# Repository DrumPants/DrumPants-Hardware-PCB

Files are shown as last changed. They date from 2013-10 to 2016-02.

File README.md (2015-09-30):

DrumPants Wearable Controller PCB
================================================

DrumPants is a wearable musical instrument and controller. 

http://www.drumpants.com

For firmware source code, see http://developers.drumpants.com

Features
--------------------------

* Sends MIDI messages over native USB 
* Bluetooth module
* MIDI synthesizer chip
* I2C EEPROM Storage
* 7-segment LED Display 
* Encoder knob and volume buttons
* Arduino Due Compatible

Credits
==========================

* Electrical Engineering and Design: Shaun Houlihan / Hedlabs (http://www.hedlabs.com/)
* Architecture and Firmware Engineering: Tyler Freeman / DrumPants
* Industrial Design: John Sundermeyer / Pull Creative (http://www.pullcreative.com)
* Sensor Design and Manufacturing: Lei Yu / DrumPants

Based on the Arduino Due

License
==========================

Copyright 2013-2015 DrumPants, Inc.
  
http://www.drumpants.com

Please see LICENSE.txt for copying and licensing info.

Licensed under the Creative Commons Attribution-ShareAlike license:

    http://creativecommons.org/licenses/by-sa/3.0/legalcode

Unless required by applicable law or agreed to in writing, software
distributed under the License is distributed on an "AS IS" BASIS,
WITHOUT WARRANTIES OR CONDITIONS OF ANY KIND, either express or implied.
See the License for the specific language governing permissions and
limitations under the License.

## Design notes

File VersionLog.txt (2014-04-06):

----IN WORK VERSION

PCB Version A0
Case Version A0

----CHANGES TO MAKE

resistor values for display change
resistor values for inputs change

----CHANGES MADE
Remove JTAG
Rename encoder nets
Ground encoder common
Bluetooth enable pin to digital IO
Added Tab Holes for USB Connector
Cutouts on PCB for Encoder
Fix power nets
Add battery solder pads

----FUTURE CHANGES

REMOVE RTC CRYSTAL?
SMALLER MCU PACKAGE
SMALLER SMD DISPLAY
SMALLER ENCODER
ENCODER POWER ON/OFF

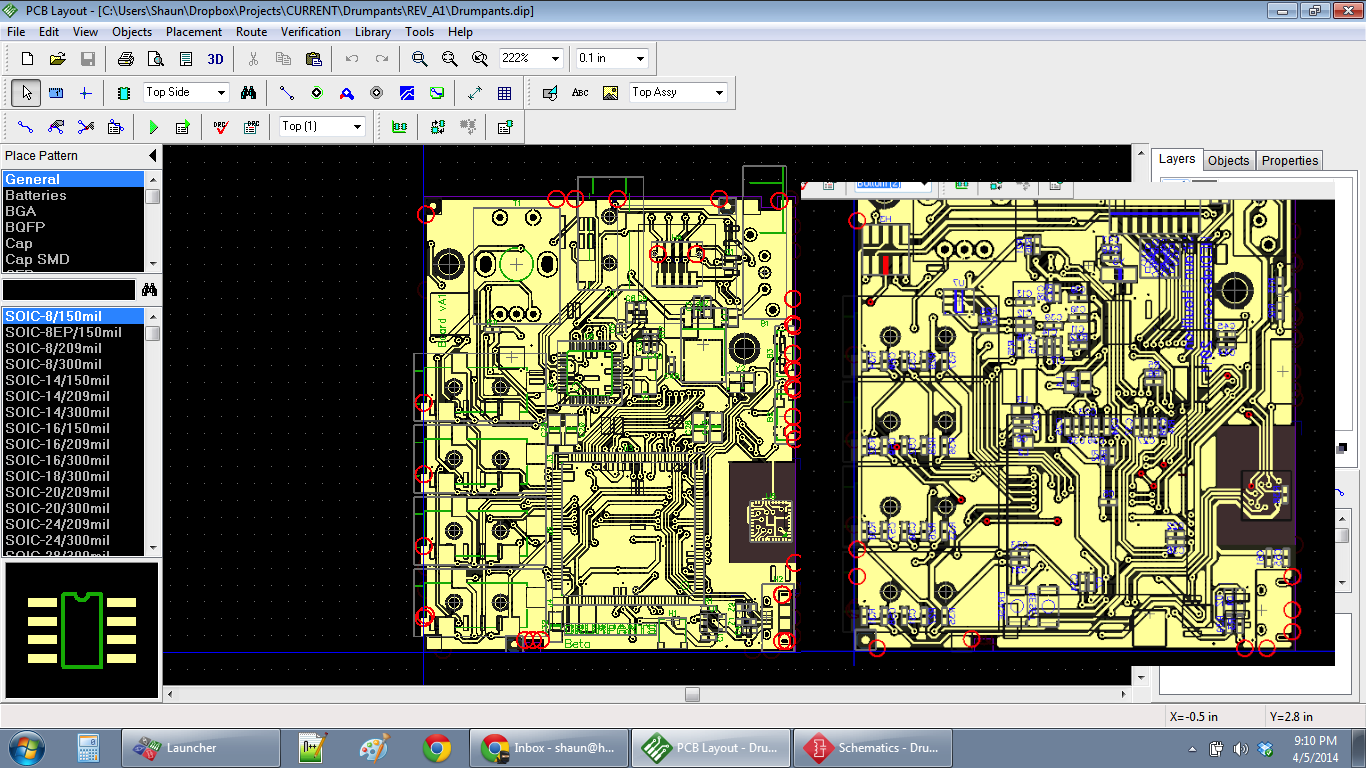
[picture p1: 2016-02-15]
beta board A1 - layout TOP.png

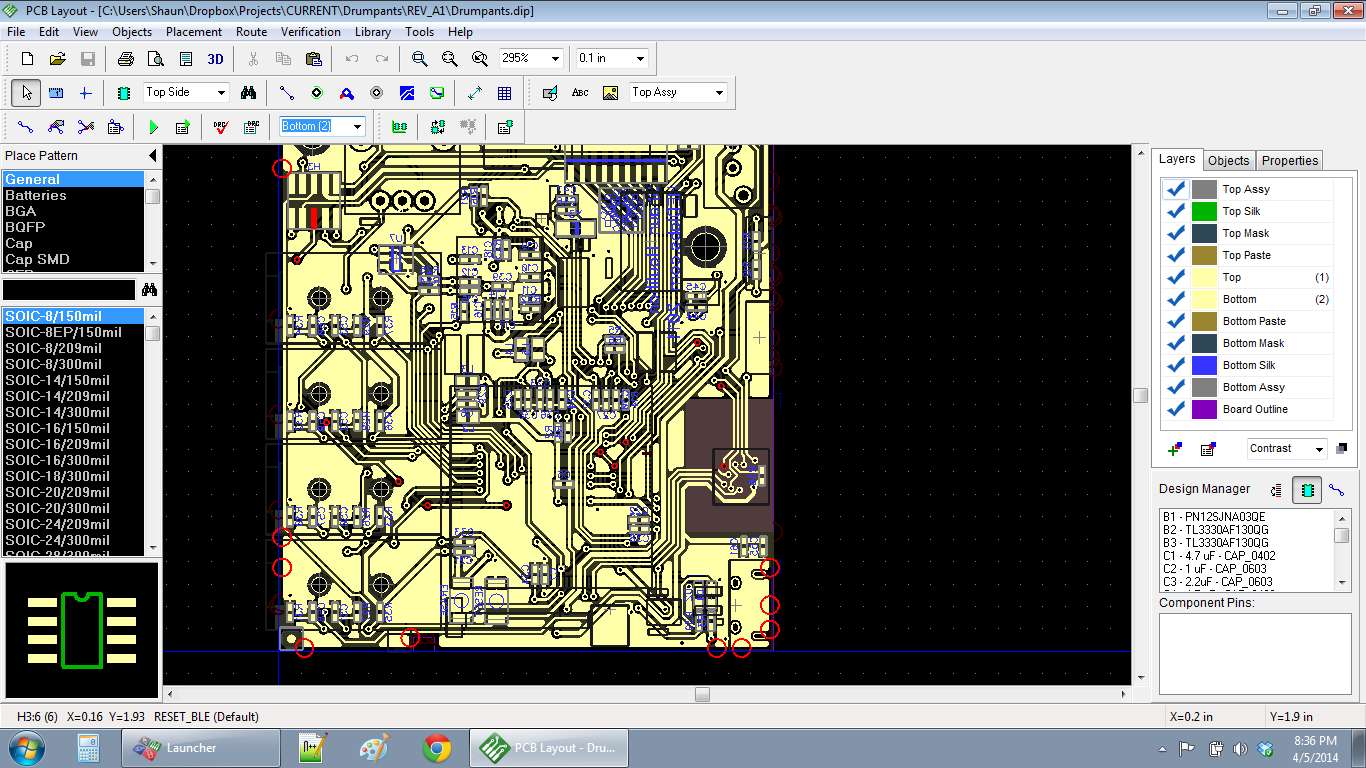
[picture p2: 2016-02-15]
beta board A1 - layout BOTTOM.png

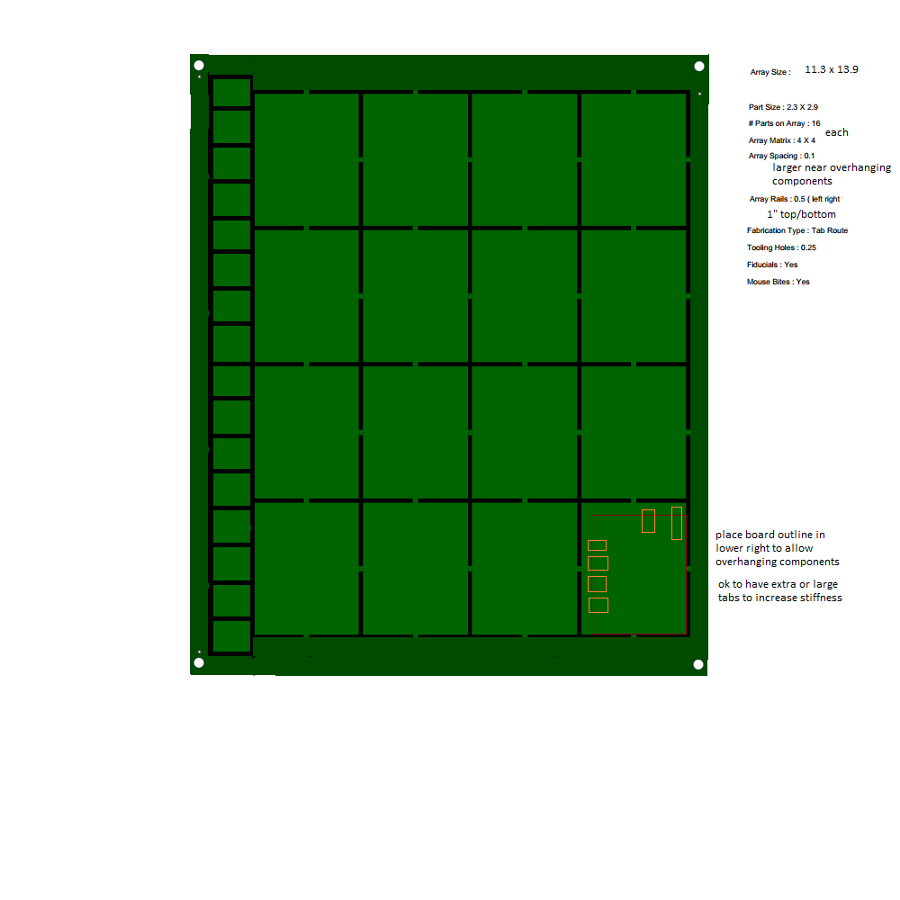
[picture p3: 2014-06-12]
panel.png

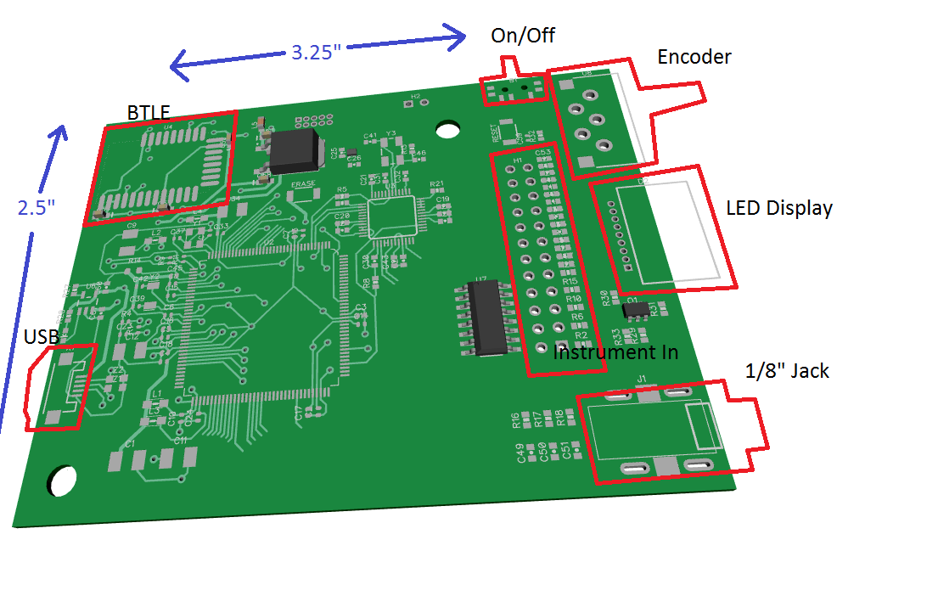
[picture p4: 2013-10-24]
Records/Layout3D.png

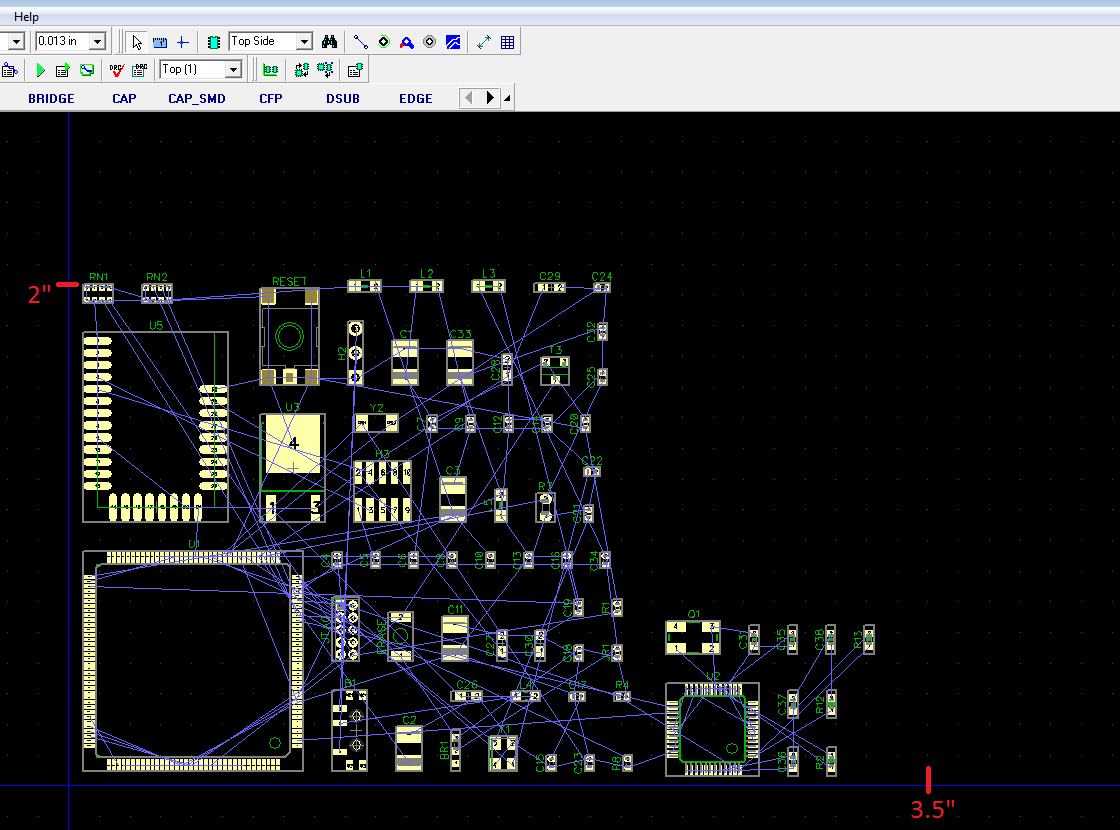
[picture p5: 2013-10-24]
Records/InitialSizing.png

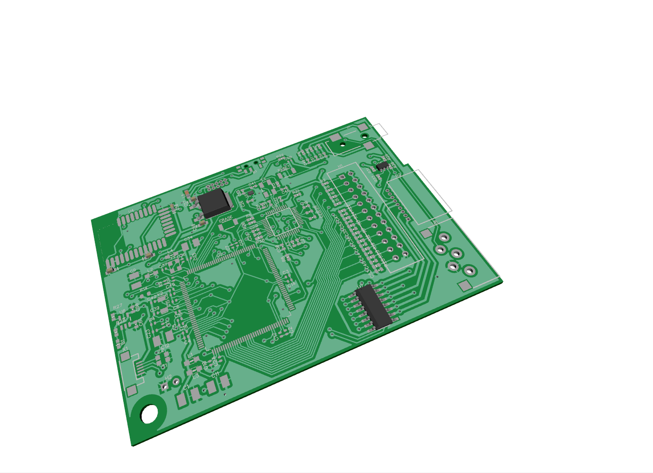
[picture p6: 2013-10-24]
Records/3D_10-24-2013.png

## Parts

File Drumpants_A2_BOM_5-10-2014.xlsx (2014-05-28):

RefDes | Name | Quantity | Value | Pattern | Pattern Type | Manufacturer | Mfg Part Number | Reel Size
B1 | SWITCH PUSH SPDT 0.3A 30V | 1 | LC1258EENP | LC1258EENP | THRU | E-Switch | LC1258EENP | 1600
D1 | LED_0603 YELLOW | 1 | LTST-C190KSKT | DIODE_0603 | SMD | Lite-On | LTST-C190KSKT | 3000
D2 | LED_0603 GREEN | 1 | LTST-C190GKT | DIODE_0603 | SMD | Lite-On | LTST-C190GKT | 3000
B2, B3 | SWITCH TACTILE SPST-NO 0.05A 12V | 2 | TL3330AF130QG | TL3330AF130QG | SMD | E-Switch (http://www.e-switch.com/) | TL3330AF130QG | 2300
C1, C4, C55 | CAP_0402 | 3 | 4.7 uF | CAP_0402 | SMD | Samsung EM | CL05A475MQ5NRNC | 10000
C2, C8, C9 | CAP_0603 | 3 | 1 uF | CAP_0603 | SMD | Samsung EM | CL10B105KQ8NNNC | 4000
C20, C26, C28, C32, C49 | CAP TANT 10UF 6.3V 10% 1206 | 5 | 10 uF | CAP_1206 | SMD | Kemet (http://www.kemet.com/) | T491A106K006AT7280 | 9000
C3 | CAP_0603 | 1 | 2.2uF | CAP_0603 | SMD
C30, C44, C45 | CAP_0402 | 3 | 22 pF | CAP_0402 | SMD
C31, C40 | CAP_0402 | 2 | 18pF | CAP_0402 | SMD
C41 | CAP_0402 | 1 | 0.047 uF | CAP_0402 | SMD
C5, C42, C43 | CAP_0402 | 3 | 10k pF | CAP_0402 | SMD
C50, C51, C52, C53, C57, C58, C59, C60 | CAP_0402 | 8 | 10 pF | CAP_0402 | SMD
C6, C7, C10, C11, C12, C13, C14, C15, C16, C17, C18, C19, C21, C22, C23, C24, C25, C27, C29, C33, C34, C35, C36, C37, C38, C39, C48, C61 | CAP_0402 | 28 | 0.1 uF | CAP_0402 | SMD
D100 | 0.3" DOUBLE DIGIT RED SMD LED | 1 | ACDA03 | ACDA04 | SMD | Kingbright (http://www.kingbrightusa.com/) | ACDA03-41SYKWA-F01 | 300
H100 | CONN HEADER 10POS DUAL SHRD SMD | 1 | 20021221-00010C4LF | 1.27MM PITCH 2x5 | SMD | FCI (http://www.te.com/en/home.html) | 20021221-00010C4LF | 500
H2 | CONN USB MICRO B RECPT SMT R/A | 1 | 10118194-0001LF | USB MICRO B 10118194-0001LF | SMD | FCI (http://portal.fciconnect.com/portal/page/portal/fciconnect/homepage) | 10118194-0001LF | 1200
H4 | CONN HEADR 0.049" 10POS SMT TIN | 1 | 20021121-00010T4LF | 1.27MM PITCH 2x5 | SMD | FCI (http://www.te.com/en/home.html) | 20021121-00010T4LF | N/A
H5 | CONN HEADER 3POS 1.25MM R/A SMD | 1 | 532610371 | 532610371 | SMD | Molex | 532610371 | 1000
J1 | CONN JACK STEREO 3.5MM SMD | 1 | 35RASMT2BHNTRX | SJ-3503-SMT-TR | SMD | Switchcraft Inc. (http://www.switchcraft.com/) | 35RASMT2BHNTRX | 1100
J2, J3, J4, J5 | CONN AUDIO JACK 3.5MM 4COND SMD | 4 | SJ-43515TS-SMT-TR | SJ-43515TS-SMT-TR | SMD | CUI Inc. (http://www.cui.com/) | SJ-43515TS-SMT-TR | 2000
L1 | FERRITE CHIP 1000 OHM 500MA 0805 | 1 | FB 1kOhm | IND_0805 | SMD | Samsung EM | CIM21J102NE | 4000
L2, L3, L4, L5 | BEAD FERRITE 30 OHM 3A | 4 | MH2029-300Y | IND_0805 | SMD | Bourns Inc. (http://www.bourns.com/) | MH2029-300Y | 4000
Q1 | TRANS DUAL NPN 30V 1A 6HUSON | 1 | PBSS4130PAN,115 | SOT1118 | LEADLESS | NXP (http://www.nxp.com/) | PBSS4130PAN,115 | 3000
R1 | RES_0402 | 1 | 2k | RES_0402 | SMD
R14 | RES_0402 | 1 | 6k8 | RES_0402 | SMD
R18 | RES_0402 | 1 | 10 | RES_0402 | SMD
R19, R20 | RES_0402 | 2 | 20 | RES_0402 | SMD
R2, R15, R16, R17, R21, R22, R23 | RES_0402 | 7 | 100k | RES_0402 | SMD
R24, R25 | RES_0402 | 2 | 10k | RES_0402 | SMD
R26, R27, R28, R29, R30, R31, R32, R34 | RES_0402 | 8 | 1M | RES_0402 | SMD
R33, R35, R36, R37 | RES_0402 | 4 | 470 | RES_0402 | SMD
R5, R6 | RES_0402 | 2 | 39 | RES_0402 | SMD
R7, R10, R3, R39 | RES_0402 | 4 | 100 | RES_0402 | SMD
R8, R9, R11, R12, R13 | RES_0402 | 5 | 4k7 | RES_0402 | SMD
T1 | 11mm Rotary Encoder | 1 | ACZ11BR4E-15FD1-20C | ACZ11BR4E | THRU | BI Technologies (http://www.bitechnologies.com/) | EN11-HSB1AQ15 | N/A
U1 | IC CONTROLLR LI-ION 4.2V SOT23-5 | 1 | MCP73831 | SOT23-5 | SMD | Microchip (http://www.microchip.com/) | MCP73831T-2ACI/OT | 3000
U2 | IC REG LDO 3.3V 0.8A DPAK | 1 | LD39080DT33-R | TO252-3(4)/10x6.6x2.28 | SMD | STMicro (http://www.st.com/web/en/home.html) | LD39080DT33-R | 2500
U3 | IC MCU 32BIT 512KB FLASH 144LQFP | 1 | ATSAM3X8EA-AU | 144LQFP | SMD | Atmel (http://www.atmel.com/) | ATSAM3X8EA-AU | N/A
U4 | TRANS 8 NPN DARL 50V 500MA 18SOL | 1 | ULN2803A | SOIC-18/300mil | SMD | Toshiba Semicond (http://www.toshiba.com/taec/) | ULN2803AFWG(C,ELHA | 1000
U5 | IC REG LDO 1.8V 0.2A 6XSON | 1 | LD6806F/18P,115 | SOT886 | LEADLESS | NXP (http://www.nxp.com/) | LD6806F/18P,115 | 5000
U6 | VS1053 | 1 | VS1053 | LQFP-48 | SMD | VLSI (http://www.vlsi.fi/en/home.html) | VS1053 | 1000
U7 | IC EEPROM 4KBIT 400KHZ SOT23-5 | 1 | 24LC04BT-I/OT | SOT-23-5 | SMD | Microchip | 24LC04BT-I/OT | 3000
U8 | BCM20732S | 1 | BCM20732S | BCM20732S | LEADLESS | Broadcom (http://www.broadcom.com/) | BCM20732S | 377
Y1 | CRYSTAL 12.288MHZ 20PF SMD | 1 | 7B-12.288MBBK-T | CRYSTAL-SMD-5X3 | SMD | TXC Corporation (http://www.txc.com.tw/en/index.asp) | 7B-12.288MBBK-T | 1000
Y2 | CRYSTAL 12MHZ 12PF SMD | 1 | 7V-12.000MAAE-T | TXC7V | SMD | TXC Corporation (http://www.txc.com.tw/en/index.asp) | 7V-12.000MAAE-T | 3000
Z1, Z2 | VARISTOR_0603 | 2 | CG0603MLC-05E | VARISTOR_0603 | SMD | Bourns Inc. (http://www.bourns.com/) | CG0603MLC-05E | 5000

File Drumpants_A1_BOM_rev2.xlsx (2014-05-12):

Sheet: BOARD
RefDes | Name | Quantity | Value | Pattern | Pattern Type | Manufacturer | Mfg Part Number | Reel Size | Reqd Reels | Extra From Reel | Distributer A | Distributer A Part Number | Price/Reel A | Reel Price Ext A | Price/Each A | Ind Price Ext A | Lead Time Wks A | Distributer B | Distributer B Part Number | Price/Reel B | Price Ext B | Lead Time Wks B | Cheapest Price
C6, C7, C10, C11, C12, C13, C14, C15, C16, C17, C18, C19, C21, C22, C23, C24, C25, C27, C29, C33, C34, C35, C36, C37, C38, C39, C48, C61 | CAP_0402 | 27 | 0.1 uF | CAP_0402 | SMD | Samsung EM | CL05A104MP5NNNC | 10000 | 3 | 3000 | Digikey | 1276-1443-2-ND | $21.00 | $63.00 | $0.003 | $81.00 | 0 |  |  |  |  |  | $21.00
C50, C51, C52, C53, C57, C58, C59, C60 | CAP_0402 | 8 | 10 pF | CAP_0402 | SMD | Samsung EM | CL05C100JB5NNNC | 10000 | 1 | 2000 | Digikey | 1276-1139-2-ND | $22.68 | $22.68 | $0.00324 | $25.92 | 0 |  |  |  |  |  | $22.68
R26, R27, R28, R29, R30, R31, R32, R34 | RES_0402 | 8 | 1M | RES_0402 | SMD | Samsung EM | RC1005J105CS | 10000 | 1 | 2000 | Digikey | 1276-4448-2-ND | $13.04 | $13.04 | $0.0023 | $18.40 | 0 |  |  |  |  |  | $13.04
R2, R15, R16, R17, R21, R22, R23 | RES_0402 | 7 | 100k | RES_0402 | SMD | Samsung EM | RC1005F104CS | 10000 | 1 | 3000 | Digikey | 1276-3432-2-ND | $14.36 | $14.36 | $0.0035 | $24.50 | 0 |  |  |  |  |  | $14.36
C2, C8, C9 | CAP_0603 | 6 | 1 uF | CAP_0603 | SMD | Samsung EM | CL10B105KQ8NNNC | 4000 | 2 | 2000 | Digikey | 1276-1024-2-ND | $31.28 | $62.56 | $0.01 | $61.20 | 0 |  |  |  |  |  | $31.28
C30, C44, C45, C46, C47 | CAP_0402 | 5 | 22 pF | CAP_0402 | SMD | Samsung EM | CL05C220JB5NNNC | 10000 | 1 | 5000 | Digikey | 1276-1116-2-ND | $22.68 | $22.68 | $0.00324 | $16.20 | 0 |  |  |  |  |  | $16.20
C20, C26, C28, C32, C49 | CAP TANT 10UF 6.3V 10% 1206 | 5 | 10 uF | CAP_1206 | SMD | Kemet (http://www.kemet.com/) | T491A106K006AT7280 | 9000 | 1 | 4000 | Digikey | 399-10116-2-ND | $576.00 | $576.00 | $0.09 | $460.00 | 0 |  |  |  |  |  | $460.00
R8, R9, R11, R12, R13 | RES_0402 | 5 | 4k7 | RES_0402 | SMD | Samsung EM | RC1005J472CS | 10000 | 1 | 5000 | Digikey | 1276-4392-2-ND | $13.04 | $13.04 | $0.00254 | $12.70 | 0 |  |  |  |  |  | $12.70
L2, L3, L4, L5 | BEAD FERRITE 30 OHM 3A | 4 | MH2029-300Y | IND_0805 | SMD | Bourns Inc. (http://www.bourns.com/) | MH2029-300Y | 4000 | 1 | 0 | Digikey | MH2029-300YCT-ND | $61.44 | $61.44 | $0.02 | $80.24 | no reels stock |  |  |  |  |  | $61.44
R33, R35, R36, R37 | RES_0402 | 4 | 470 | RES_0402 | SMD | Samsung EM | RC1005F471CS | 10000 | 1 | 6000 | Digikey | 1276-3989-2-ND | $14.36 | $14.36 | $0.00254 | $10.16 | 0 |  |  |  |  |  | $10.16
J2, J3, J4, J5 | CONN AUDIO JACK 3.5MM 4COND SMD | 4 | SJ-43515TS-SMT-TR | SJ-43515TS-SMT-TR | SMD | CUI Inc. (http://www.cui.com/) | SJ-43515TS-SMT-TR | 2000 | 2 | 0 | Digikey | CP-43515TSSJTR-ND | $1067.20 | $2134.40 | $0.73 | $2914.56 | 0 | Future Electronics |  |  |  |  | $1067.20
R3, R7, R10, R39 | RES_0402 | 3 | 680 | RES_0402 | SMD | Samsung EM | RC1005J681CS | 10000 | 1 | 7000 | Digikey | 1276-4372-2-ND | $13.04 | $13.04 | $0.00254 | $7.62 | 0 |  |  |  |  |  | $7.62
C1, C4, C55 | CAP_0402 | 3 | 4.7 uF | CAP_0402 | SMD | Samsung EM | CL05A475MQ5NRNC | 10000 | 1 | 7000 | Digikey | 1276-1056-2-ND | $366.70 | $366.70 | $0.05 | $147.66 | 0 |  |  |  |  |  | $147.66
C5, C42, C43 | CAP_0402 | 2 | 10k pF | CAP_0402 | SMD | Samsung EM | CL05B103KB5NNNC | 10000 | 1 | 8000 | Digikey | 1276-1028-2-ND | $21.63 | $21.63 | $0.00309 | $6.18 | 0 |  |  |  |  |  | $6.18
C31, C40 | CAP_0402 | 2 | 18pF | CAP_0402 | SMD | Samsung EM | CL05C180JB5NNNC | 10000 | 1 | 8000 | Digikey | 1276-1140-2-ND | $22.68 | $22.68 | $0.00324 | $6.48 | 0 |  |  |  |  |  | $6.48
R5, R6 | RES_0402 | 2 | 39 | RES_0402 | SMD | Samsung EM | RC1005F390CS | 10000 | 1 | 8000 | Digikey | 1276-3463-2-ND | $14.85 | $14.85 | $0.00254 | $5.08 | 0 |  |  |  |  |  | $5.08
R19, R20 | RES_0402 | 2 | 20 | RES_0402 | SMD | Samsung EM | RC1005J200CS | 10000 | 1 | 8000 | Digikey | 1276-4335-2-ND | $13.04 | $13.04 | $0.00254 | $5.08 | 0 |  |  |  |  |  | $5.08
R24, R25, R38 | RES_0402 | 2 | 10k | RES_0402 | SMD | Samsung EM | RC1005F103CS | 10000 | 1 | 8000 | Digikey | 1276-3431-2-ND | $14.36 | $14.36 | $0.00254 | $5.08 | 0 |  |  |  |  |  | $5.08
B2, B3 | SWITCH TACTILE SPST-NO 0.05A 12V | 2 | TL3330AF130QG | TL3330AF130QG | SMD | E-Switch (http://www.e-switch.com/) | TL3330AF130QG | 2300 | 1 | 300 | Digikey | EG4388TR-ND | $520.95 | $520.95 | $0.25 | $498.30 | 0 |  |  |  |  |  | $498.30
Z1, Z2 | VARISTOR_0603 | 2 | CG0603MLC-05E | VARISTOR_0603 | SMD | Bourns Inc. (http://www.bourns.com/) | CG0603MLC-05E | 5000 | 1 | 3000 | Digikey | CG0603MLC-05ETR-ND | $390.00 | $390.00 | $0.10 | $206.96 | 0 |  |  |  |  |  | $206.96
J1 | CONN JACK STEREO 3.5MM SMD | 1 | 35RASMT2BHNTRX | SJ-3503-SMT-TR | SMD | Switchcraft Inc. (http://www.switchcraft.com/) | 35RASMT2BHNTRX | 1100 | 1 | 100 | Digikey | 35RASMT2BHNTRX | $646.80 | $646.80 | $0.61 | $610.00 | 0 |  |  |  |  |  | $610.00
Y1 | CRYSTAL 12.288MHZ 20PF SMD | 1 | 7B-12.288MBBK-T | CRYSTAL-SMD-5X3 | SMD | TXC Corporation (http://www.txc.com.tw/en/index.asp) | 7B-12.288MBBK-T | 1000 | 1 | 0 | Digikey | 887-1892-2-ND | $390.00 | $390.00 | $0.49 | $491.40 | 0 |  |  |  |  |  | $390.00
Y2 | CRYSTAL 12MHZ 12PF SMD | 1 | 7V-12.000MAAE-T | TXC7V | SMD | TXC Corporation (http://www.txc.com.tw/en/index.asp) | 7V-12.000MAAE-T | 3000 | 1 | 2000 | Digikey | 887-1458-1-ND | $1305.00 | $1305.00 | $0.47 | $474.00 | 0 |  |  |  |  |  | $474.00
H4 | CONN HEADR 0.049" 10POS SMT TIN | 1 | 4-174821-0 | 1.25MM PITCH 2x5 | SMD | TE Connectivity (http://www.te.com/en/home.html) | 4-174821-0 | N/A | #VALUE! | #VALUE! | Digikey | 4-174821-0-ND | N/A | $0.00 | $0.36 | $356.40 | 0 |  |  |  |  |  | $356.40
U3 | IC MCU 32BIT 512KB FLASH 144LQFP | 1 | ATSAM3X8EA-AU | 144LQFP | SMD | Atmel (http://www.atmel.com/) | ATSAM3X8EA-AU | ?? | #VALUE! | #VALUE! | Mouser | ATSAM3X8EA-AU | ?? | #VALUE! | $7.68 | $7680.00 | 7 |  |  |  |  |  | $7680.00
U8 | BCM20732S | 1 | BCM20732S | BCM20732S | LEADLESS | Broadcom (http://www.broadcom.com/) | BCM20732S | 377 | 3 | 131 | AVNET (http://www.avnet.com/) | BCM20732S | $1470.30 | $4410.90 | $3.90 | $3900.00 | 0 |  |  |  |  |  | $1470.30
H1 | CONN HEADER ACH SIDE 2POS 1.2MM | 1 | BM02B-ACHSS-GAN-ETF | BM02B-ACHSS-GAN-ETF | SMD | JST (http://www.jst.com/) | BM02B-ACHSS-GAN-TF(LF)(SN) | 4500 | 1 | 3500 | Digikey | 455-2202-2-ND | $1092.56 | $1092.56 | $0.29 | $293.78 | 0 |  |  |  |  |  | $293.78
C41 | CAP_0402 | 1 | 0.047 uF | CAP_0402 | SMD | Samsung EM | CL05B473KO5NNNC | 10000 | 1 | 9000 | Digikey | 1276-1077-2-ND | $25.20 | $25.20 | $0.0036 | $3.60 | 0 |  |  |  |  |  | $3.60
C3 | CAP_0603 | 1 | 2.2uF | CAP_0603 | SMD | Samsung EM | CL10A225KQ8NNNC | 4000 | 1 | 3000 | Digikey | 1276-1183-2-ND | $68.80 | $68.80 | $0.02 | $22.00 | 0 |  |  |  |  |  | $22.00
T1 | 11mm Rotary Encoder | 1 | EN11-HSB1AQ15 | EN11-HSB | THRU | BI Technologies (http://www.bitechnologies.com/) | EN11-HSB1AQ15 | ?? | #VALUE! | #VALUE! | Mouser | 858-EN11-HSB1AQ15 | ?? | #VALUE! | $0.84 | $838.00 | find alt dist |  |  |  |  |  | $838.00
L1 | FERRITE CHIP 1000 OHM 500MA 0805 | 1 | FB 1kOhm | IND_0805 | SMD | Samsung EM | CIM21J102NE | 4000 | 1 | 3000 | Digikey | 1276-6331-2-ND | $45.36 | $45.36 | $0.01 | $14.66 | 0 |  |  |  |  |  | $14.66
U2 | IC REG LDO 3.3V 0.8A DPAK | 1 | LD39080DT33-R | TO252-3(4)/10x6.6x2.28 | SMD | STMicro (http://www.st.com/web/en/home.html) | LD39080DT33-R | 2500 | 1 | 1500 | Digikey | 497-6015-2-ND | $1771.88 | $1771.88 | $0.78 | $782.25 | 0 |  |  |  |  |  | $782.25
U5 | IC REG LDO 1.8V 0.2A 6XSON | 1 | LD6806F/18P,115 | SOT886 | LEADLESS | NXP (http://www.nxp.com/) | LD6806F/18P,115 | 5000 | 1 | 4000 | Digikey | 568-10019-2-ND | $768.50 | $768.50 | $0.19 | $185.50 | 0 |  |  |  |  |  | $185.50
U1 | IC CONTROLLR LI-ION 4.2V SOT23-5 | 1 | MCP73831 | SOT23-5 | SMD | Microchip (http://www.microchip.com/) | MCP73831T-2ACI/OT | 3000 | 1 | 2000 | Digikey | MCP73831T-2ACI/OTTR-ND | $1260.00 | $1260.00 | $0.42 | $420.00 | 0 |  |  |  |  |  | $420.00
Y3 | CRYSTAL 32.768KHZ 9PF SMD | 1 | CM315D32768DZCT | OSC_1206 | SMD | Citizen Finetech (http://cfm.citizen.co.jp/english/) | CM315D32768DZCT | 3000 | 1 | 2000 | Digikey | 300-8813-2-ND | $1377.00 | $1377.00 | $0.51 | $510.00 | 0 |  |  |  |  |  | $510.00
Q1 | TRANS DUAL NPN 30V 1A 6HUSON | 1 | PBSS4130PAN,115 | SOT1118 | LEADLESS | NXP (http://www.nxp.com/) | PBSS4130PAN,115 | 3000 | 1 | 2000 | Digikey | 568-10197-2-ND | $538.00 | $538.00 | $0.20 | $202.83 | 0 |  |  |  |  |  | $202.83
B1 | SWITCH PUSH SPDT 0.3A 30V | 1 | LC1258EENP | LC1258EENP | THRU | E-Switch | LC1258EENP | 1600 | 1 | 600 | Mouser | 612-LC1258EENP | $816.00 | $816.00 | $0.56 | $560.00 | 2 | Future Electronics |  |  |  |  | $560.00
R1 | RES_0402 | 1 | 2k | RES_0402 | SMD | Samsung EM | RC1005F202CS | 10000 | 1 | 9000 | Digikey | 1276-3448-2-ND | $14.36 | $14.36 | $0.00254 | $2.54 | 0 |  |  |  |  |  | $2.54
R14 | RES_0402 | 1 | 6k8 | RES_0402 | SMD | Samsung EM | RC1005F682CS | 10000 | 1 | 9000 | Digikey | 1276-4098-2-ND | $14.36 | $14.36 | $0.00254 | $2.54 | 0 |  |  |  |  |  | $2.54
R18 | RES_0402 | 1 | 10 | RES_0402 | SMD | Samsung EM | RC1005F100CS | 10000 | 1 | 9000 | Digikey | 1276-3428-2-ND | $19.80 | $19.80 | $0.0035 | $3.50 | 0 |  |  |  |  |  | $3.50
U4 | TRANS 8 NPN DARL 50V 500MA 18SOL | 1 | ULN2803A | SOIC-18/300mil | SMD | Toshiba Semicond (http://www.toshiba.com/taec/) | ULN2803AFWG(C,ELHA | 1000 | 1 | 0 | Digikey | ULN2803AFWG(CELHATR-ND | $304.50 | $304.50 | $0.37 | $367.50 | find alt PN |  |  |  |  |  | $304.50
H2 | CONN USB MICRO B RECPT SMT R/A | 1 | 10118194-0001LF | USB MICRO B 10118194-0001LF | SMD | FCI (http://portal.fciconnect.com/portal/page/portal/fciconnect/homepage) | 10118194-0001LF | 1200 | 1 | 200 | Digikey | 609-4618-2-ND | $236.25 | $236.25 | $0.26 | $259.88 | find alt PN |  |  |  |  |  | $236.25
U6 | VS1053 | 1 | VS1053 | LQFP-48 | SMD | VLSI (http://www.vlsi.fi/en/home.html) | VS1053 | 1000 | 1 | 0 | VLSI | VS1053 | $3440.00 | $3440.00 | $3.44 | $3440.00 | 0 |  |  |  |  |  | $3440.00
U7 | IC EEPROM 1KBIT 400KHZ SOT23-5 | 1 | 24LC01BT-I/OT | SOT23-5 | SOT23-5 | Microchip | 24LC01BT-I/OT | 3000 | 1 | 2000 | Digikey | 24LC01BT-I/OTTR-ND | 510 | $510.00 | $0.17 | $170.00 | 0 |  |  |  |  |  | $170.00
D1, D2 | LED_0603 | 0 | NP | DIO_0603 | SMD | N/A | N/A | N/A | #VALUE! | #VALUE! | N/A | N/A | N/A | #VALUE! |  | $0.00 | N/A |  |  |  |  |  | $0.00
ERASE, RESET | MYSMD_PB157 | 0 | NP | SMD_157SW | N/A | N/A | N/A | N/A | #VALUE! | #VALUE! | N/A | N/A | N/A | #VALUE! |  | $0.00 | N/A |  |  |  |  |  | $0.00
H3 | HEADER,5X2,M,1.27,SMD | 0 | NP | 5x2 1.27 | N/A | N/A | N/A | N/A | #VALUE! | #VALUE! | N/A | N/A | N/A | #VALUE! |  | $0.00 | N/A |  |  |  |  |  | $0.00
R4 | RES_0402 | 0 | NP | RES_0402 | N/A | N/A | N/A | N/A | #VALUE! | #VALUE! | N/A | N/A | N/A | #VALUE! |  | $0.00 | N/A |  |  |  |  |  | $0.00
 |  |  |  |  |  |  |  |  |  |  |  |  |  |  |  |  |  |  |  |  |  |  | $21591.15

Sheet: BREAKOUT
D1 | 0.3" DOUBLE DIGIT RED SMD LED | 1 | ACDC03-41SRWA-F01 | ACDC03-41SRWA-F01 | SMD | Kingbright (http://www.kingbrightusa.com/) | ACDC03-41SRWA-F01 | 300 | #VALUE! | #VALUE! | WPG Americas (http://www.wpgamericas.com/) | ?? | ?? | #VALUE! | $1.75 | #VALUE! | 0 | #VALUE!
H1 | CONN RCPT 10POS DUAL VERT SMD | 1 | 4-175638-0 | 1.25MM PITCH 2x5 | SMD | TE Connectivity (http://www.te.com/en/home.html) | 4-175638-0 | 1500 | 3 | 3000 | Digikey | A100883TR-ND | 836.64 | $63.00 | 0.73624 | $81.00 | no reels stock | $21.00

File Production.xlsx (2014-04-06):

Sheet: TIMELINE
 |  |  |  |  |  |  | REVISION | COLOR | QTY RANGE
 |  |  |  |  |  |  | A |  | 10 | 20
 |  |  |  |  |  |  | B |  | 300 | 10000
 |  |  |  |  |  |  | C |  | 5000 | 100000
 |  |  |  |  |  |  | JANUARY |  |  |  | FEBRUARY |  |  |  | MARCH |  |  |  | APRIL |  |  |  | MAY |  |  |  | JUNE
GOAL | TIME | $FEE | $TOOL | $UNIT | NUM | $EXT | 1 | 2 | 3 | 4 | 1 | 2 | 3 | 4 | 1 | 2 | 3 | 4 | 1 | 2 | 3 | 4 | 1 | 2 | 3 | 4 | 1 | 2 | 3 | 4
Minor PCB changes | 5 |  |  |  |  |  | 5
Moldable case design for A | 6 |  |  |  |  |  | 6
Build and populate batch of REV A PCBs | 5 |  | $300 | $50 | 120 | $6000 | 5 | 0 | 0
Fabricate REV A cases - print vs. urethane casting | 5 |  | $1000 | $20 | 120 | $2400 |  | 5 | 0
A COSTS | 21 | $1575 | $1300 |  |  | $8400
REV B planning & estimation - optimization/supply chain/features/power | 35 |  |  |  |  |  |  | 7 | 7 | 7 | 7 | 7
Industrial Design - case/materials/cables/connectors/interfaces/fabric | 18 |  |  |  |  |  |  | 3 | 3 | 3 | 3 | 3 | 3
PCB B Layout | 32 |  |  |  |  |  |  |  |  |  | 8 | 8 | 8 | 8
Case B Engineeirng | 28 |  |  |  |  |  |  |  |  |  | 7 | 7 | 7 | 7
Source & Order PCB Components | 8 |  |  | $35.464 | 2000 | $70928 |  |  |  |  |  |  | 4 | 2 | 2
Case B Proto/Test | 1 |  |  | $100 | 1 | $100 |  |  |  |  |  |  |  | 1 | 0
PCB B Proto/Test | 3 |  | $300 | $50 | 1 | $50 |  |  |  |  |  |  |  | 3 | 0 | 0
Case B Production Run | 5 |  | $12000 | $7 | 2000 | $14000 |  |  |  |  |  |  |  |  |  | 3 | 2 | 0
PCB B Production Run | 26 |  | $300 | $15 | 2000 | $30000 |  |  |  |  |  |  |  |  |  | 14 | 5 | 5 | 2
Cables Production Run | 0 |  | $200 | $2 | 2000 | $4000 |  |  |  |  |  |  |  |  |  | 0 | 0 | 0
Straps Production Run | 0 |  | $200 | $2 | 2000 | $4000 |  |  |  |  |  |  |  |  |  | 0 | 0 | 0
REV B final assembly & test | 10 |  |  |  |  |  |  |  |  |  |  |  |  |  |  |  |  |  | 5 | 5 | 0 | 0 | 0
Shipping REV B | 0 |  |  |  |  |  |  |  |  |  |  |  |  |  |  |  |  |  |  |  | 0 | 0 | 0 | 0 | 0 | 0
B COSTS | 166 | $12450 | $13000 |  |  | $123078
Sourcing high volume manufacturers & partners | 0
Industrial Design Push REV C | 0
Engineering changes for REV C | 0
C COSTS | 0 | 0 | 0 |  |  | 0
TOTALS | 187 | $14025 | $14300 |  |  | $131478 | 16 | 15 | 10 | 10 | 25 | 25 | 22 | 21 | 2 | 17 | 7 | 5 | 7 | 5 | 0 | 0 | 0 | 0 | 0 | 0 | 0 | 0 | 0 | 0
FULL PRODUCTION COST (2000 units) |  | $159803

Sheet: CHANGES
REV A | $11275.00
power rewiring
larger on/off switch
remove JTAG
bluetooth enable
change resistor values
cutouts for display/connectors
FC-145 replacement
REV B | $148528.00
Aesthetic refinement
Battery
Instrument Connector
Display
Encoder
Smaller MCU
EEPROM
PCB/Case Fit
Mounting/Carrying options
Panelize Board
Component sourcing verify
Optimize case for high vol prod

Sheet: FEE & COST SCHEDULE
TOOLING COSTS
 | URETHANE MOLDS/SETUP | $500
 | INJECTION MOLDS/SETUP | $6000
 | INJECTION SETUP ONLY | $300
 | PCB STENCILS/SETUP | $300
 | CABLES SETUP | $200
 | FABRIC SETUP | $200
ENGINERING
 | HOURLY | $75

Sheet: BOM
LEVEL 1 | LEVEL 2 | 1K |  | 10K
CIRCUIT BOARD |  | $50.4640 |  | $15.5000
 | E-BOM |  | $35.4640 |  | $12.0000
 | PRINTED PCB |  | $3.0000 |  | $0.5000
 | PCB ASSY |  | $12.0000 |  | $3.0000
CASE SIDE A |  | $3.5000 |  | $1.2500
CASE SIDE B |  | $3.5000 |  | $1.2500
INSTRUMENT STRAPS |  | $7.0000 |  | $0.8000
 | FABRIC |  | $3.0000 |  | $0.3000
 | CABLE |  | $4.0000 |  | $0.5000
TOTAL |  | $64.46 |  | $18.80
TOTAL EXT |  | $64464 |  | $188000

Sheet: E-BOM
REFERENCE DESCRIPTOR | DESCRIPTION | SPEC | MFG | MFG # | PATTERN | PATTERN TYPE | COMP TYPE | REEL QTY | QTY | $1K | $10K | $100K | $1K EXT | $10K EXT | $100K EXT | VENDOR | VEND # | 1K LEAD WKS
U4 | Bluetooth Low Energy Radio | BLE112 | Bluegiga | BLE112 | BLE112 | LEADLESS | IC |  | 1 | $10.1500 |  |  | $10.1500 |  |  | DIGIKEY | 1446-1017-1-ND
U2 | ARM Microcontroller | ATSAM3X8EA-AU | Atmel | ATSAM3X8EA-AU | LQFP144 | SMD | IC |  | 1 | $6.0000 |  |  | $6.0000 | 0 |  | DIGIKEY | ATSAM3X8EA-AU-ND
B1 | Battery | 860mAh |  | 063048 860mAh | Battery |  |  |  | 1 | $6.0000 |  |  | $6.0000
U3 | MIDI Chip | VS1053 | VLSI | VS1053 | LQFP-48 |  |  |  | 1 | $3.4200 |  |  | $3.4200
Y1 | CRYSTAL-3.2-2.5 | 12MHz KX-7 20pF | KX-7T REPLACEMENT | ECS-120-20-33-CKM-TR | KX-7T REPLACEMENT |  | CRYS |  | 1 | $1.7500 |  |  | $1.7500 |  |  | DIGIKEY | XC1810CT-ND
D2 | 7 Segment LED Display | LDD-F304NI-RA | Lumex Opto/Components Inc. |  | LDD-E304NI-RA |  | UI |  | 1 | $1.5200 |  |  | $1.5200
B1 | Slider Switch SPDT |  | TE Connectivity | MLL1200S | MLL1200S |  |  |  | 1 | $1.2300 |  |  | $1.2300 |  |  | DIGIKEY | 1276-6331-1-ND
Y2 | RESONATOR_EPSON_FC_145 | 32.768Khz | Epson | FC-145 32.7680KD-AC3 | RESONATOR_EPSON_FC_145 |  | CRYS |  | 1 | $0.9900 |  |  | $0.9900 |  |  | DIGIKEY | SE2413CT-ND
U5 | 3.3 Volt LDO Regulator |  | STMicroelectronics | LD39080DT33-R | TO252-3(4)/10x6.6x2.28 |  |  |  | 1 | $0.7800 |  |  | $0.7800 |  |  | DIGIKEY | 568-10198-1-ND
U8 | Rotary Pushbutton Encoder | PEC16-2115F-S0012 | Bournes | PEC16-2115F-S0012 | PEC16-2115F-S0012 |  | UI |  | 1 | $0.6770 |  |  | $0.6770 |  |  | DIGIKEY | PEC16-2115F-S0012-ND
J1 | 1/8" Headphone Jack | 35RASMT2BHNTRX | Switchcraft Inc | 35RASMT2BHNTRX | 35RASMT2BHNTRX |  |  |  | 1 | $0.6100 |  |  | $0.6100 |  |  | DIGIKEY | 475-1410-1-ND
Y3 | CRYSTAL5X3 | 12.288MHz | SPK | SPK-12M288-5032 | CRYSTAL-SMD-5X3 |  |  |  | 1 | $0.5000 |  |  | $0.5000 |  |  | DIGIKEY | 568-10019-1-ND
U6 | MCP73831 | MCP73831 | Microchip Technology | MCP73831T-2DCI/OT | SOT23-5 |  |  |  | 1 | $0.4200 |  |  | $0.4200 |  |  | DIGIKEY | 67-1516-5-ND
X1 | USB Micro B Connector | Micro USB | FCI | 10118194-0001LF | USB-MICROB |  | CON |  | 1 | $0.2500 |  |  | $0.2500 |  |  | DIGIKEY | 609-4618-1-ND
H1 | Instrument In |  | On Shore Inc. | 302-S241 | 12x2 |  | CON |  | 1 | $0.2500 |  |  | $0.2500
Z1, Z2 | VARISTORCN0603 | CG0603MLC-05E | Bournes | CG0603MLC-05E | CT/CN0603 |  | STD |  | 2 | $0.1030 |  |  | $0.2060 |  |  | DIGIKEY | CG0603MLC-05ECT-ND
Q1 | PBSS4130PAN |  | NXP | PBSS4130PAN,115 | SOT1118 |  |  |  | 1 | $0.2020 |  |  | $0.2020
U7 | ULN2003D |  | STMicroelectronics | ULN2003D1013TR | SOIC-16/150mil |  |  |  | 1 | $0.1870 |  |  | $0.1870 |  |  | DIGIKEY | ED10525-ND
U1 | LD6806F/18P,115 |  | NXP | LD6806F/18P,115 | SOT886 |  |  |  | 1 | $0.1850 |  |  | $0.1850 |  |  | DIGIKEY | MCP73831T-2DCI/OTCT-ND
L1, L2, L3, L4 | WE-CBF_0805 | MH2029-300Y | Bournes | MH2029-300Y | 805 |  |  |  | 4 | $0.0200 |  |  | $0.0800 |  |  | DIGIKEY | MH2029-300YCT-ND
D1 | LED0603 | RED | Osram Opto | LG R971-KN-1 | LED-0603 |  |  |  | 1 | $0.0430 |  |  | $0.0430
L5 | IND_0804 | FB 1kOhm | Samsung ElectroMechanics | CIM21J102NE | IND_0804 |  |  |  | 1 | $0.0140 |  |  | $0.0140
C1, C9, C11, C12, C34 | CPOL-EUSMCB | 10u |  |  | SMC_B | SMD | STD |  | 5 |  |  |  | $0.0000 |  |  | DIGIKEY | 497-2345-1-ND
C2, C3, C4, C5, C6, C7, C8, C10, C13, C14, C15, C16, C17, C18, C23, C24, C33 | C-EUC0402 | 100n |  |  | C0402 | SMD | STD |  | 17 |  |  |  | $0.0000 |  |  | DIGIKEY | SC1489-1-ND
C19, C20, C21, C22, C27, C28, C29, C30, C31, C32 | CAP0402-CAP | 100nF |  |  | 0402-CAP | SMD | STD |  | 10 |  |  |  | $0.0000 |  |  | DIGIKEY | 450-1577-ND
C25, C26 | CAP0402-CAP | 1uF |  |  | 0402-CAP | SMD | STD |  | 2 |  |  |  | $0.0000
C35, C38, C40, C44, C47, C48, C52, C53 | CAP0402-CAP | 10pf |  |  | 0402-CAP | SMD | STD |  | 8 |  |  |  | $0.0000
C36, C37, C45 | C-EUC0402 | 22p |  |  | C0402 | SMD | STD |  | 3 |  |  |  | $0.0000
C39, C42 | C-EUC0402 | 22pF_NM |  |  | C0402 | SMD | STD |  | 2 |  |  |  | $0.0000
C41, C46 | CAP0402-CAP | 18pF |  |  | 0402-CAP | SMD | STD |  | 2 |  |  |  | $0.0000
C43 | CAP0402-CAP | 0.1uF |  |  | 0402-CAP | SMD | STD |  | 1 |  |  |  | $0.0000
C49 | CAP0402-CAP | 47nF |  |  | 0402-CAP | SMD | STD |  | 1 |  |  |  | $0.0000
C50, C51 | CAP0402-CAP | 10nF |  |  | 0402-CAP | SMD | STD |  | 2 |  |  |  | $0.0000
C54, C55, C56, C57 | CAP_0603 | 1 uF |  |  | CAP_0603 | SMD | STD |  | 4 |  |  |  | $0.0000
C58 | CAP_0603 | 2.2uF |  |  | CAP_0603 | SMD | STD |  | 1 |  |  |  | $0.0000
C59 | C-EUC0402 | 10n |  |  | C0402 | SMD | STD |  | 1 |  |  |  | $0.0000
C60, C61 | CAP0402-CAP | 4.7uF |  |  | 0402-CAP | SMD | STD |  | 2 |  |  |  | $0.0000
R1 | R-EU_R0402 | 100K |  |  | R0402 | SMD | STD |  | 1 |  |  |  | $0.0000
R2, R3, R6, R7, R10, R12, R13, R15, R19, R22, R23, R24, R25 | RESISTOR0402-RES | 1M |  |  | 0402-RES | SMD | STD |  | 13 |  |  |  | $0.0000
R4 | R-EU_R0402 | 0R_NM |  |  | R0402 | SMD | STD |  | 1 |  |  |  | $0.0000
R5, R8, R20, R21, R38 | RESISTOR0402-RES | 100k |  |  | 0402-RES | SMD | STD |  | 5 |  |  |  | $0.0000
R9, R11 | R-EU_R0402 | 39R 1% |  |  | R0402 | SMD | STD |  | 2 |  |  |  | $0.0000
R14 | R-EU_R0603 | 6k8 1% |  |  | R0603-ROUND | SMD | STD |  | 1 |  |  |  | $0.0000
R16 | RESISTOR0402-RES | 10 |  |  | 0402-RES | SMD | STD |  | 1 |  |  |  | $0.0000
R17, R18 | RESISTOR0402-RES | 20 |  |  | 0402-RES | SMD | STD |  | 2 |  |  |  | $0.0000
R26 | R-EU_R0402 | 0R |  |  | R0402 | SMD | STD |  | 1 |  |  |  | $0.0000
R27 | RESISTOR0402-RES | 2K |  |  | 0402-RES | SMD | STD |  | 1 |  |  |  | $0.0000
R28 | RESISTOR0402-RES | 330 |  |  | 0402-RES | SMD | STD |  | 1 |  |  |  | $0.0000
R29, R33 | RESISTOR0402-RES | 380 |  |  | 0402-RES | SMD | STD |  | 2 |  |  |  | $0.0000
R30, R31 | RESISTOR0402-RES | 4.7K |  |  | 0402-RES | SMD | STD |  | 2 |  |  |  | $0.0000
R32 | RESISTOR0402-RES | 4.7k |  |  | 0402-RES | SMD | STD |  | 1 |  |  |  | $0.0000
R34, R35, R36, R37 | RESISTOR0402-RES | 2k2 |  |  | 0402-RES | SMD | STD |  | 4 |  |  |  | $0.0000

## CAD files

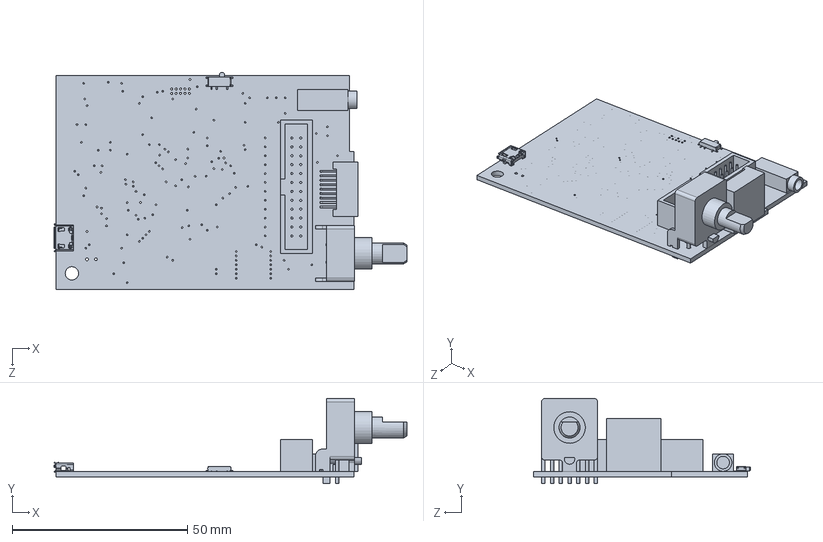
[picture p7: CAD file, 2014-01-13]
EZCase/PCBAssembly_EZ.SLDPRT
100.7 x 24.3 x 61.8 mm

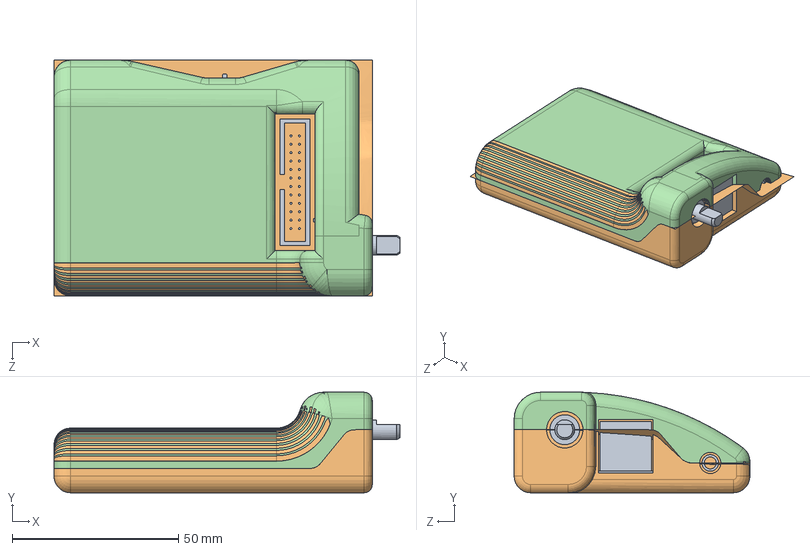
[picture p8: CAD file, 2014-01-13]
EZCase/DrumpantsCase_EZ.SLDASM
104.2 x 30.3 x 71.0 mm
PCBAssembly_EZ
CaseShape_EZ
battery_EZ

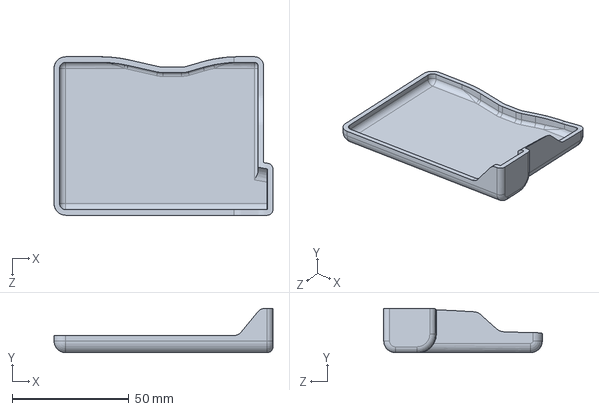
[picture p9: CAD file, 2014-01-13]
EZCase/Bottom_EZ.sldprt
93.9 x 19.0 x 68.0 mm

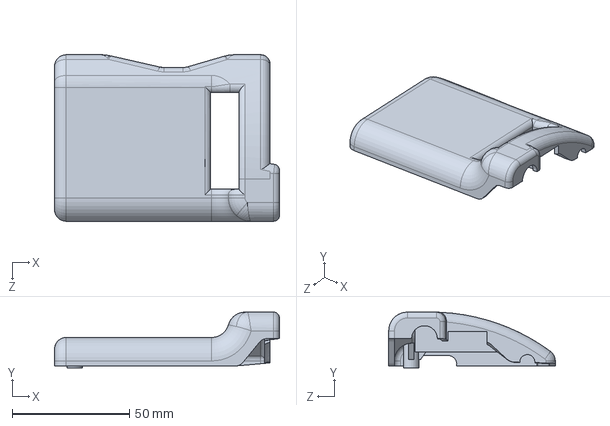
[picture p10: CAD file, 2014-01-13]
EZCase/Top_EZ.sldprt
95.8 x 23.8 x 71.0 mm

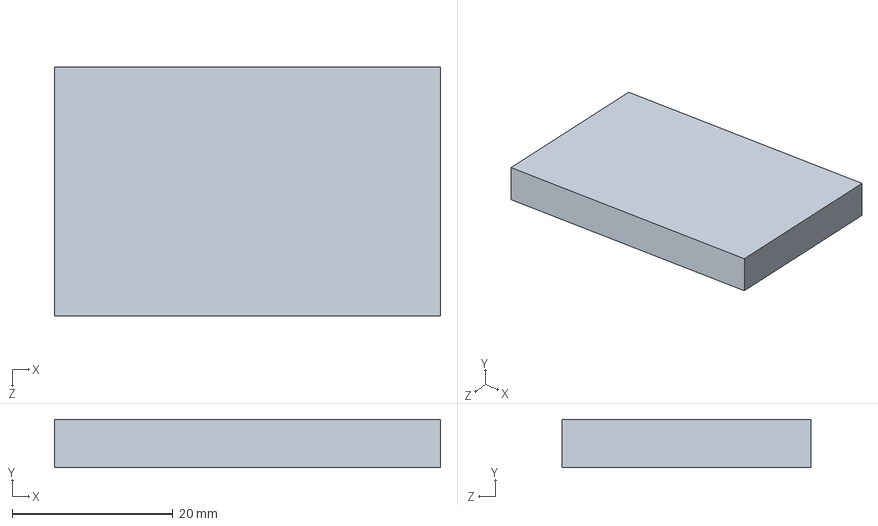
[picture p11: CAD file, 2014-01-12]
EZCase/battery_EZ.SLDPRT
48.0 x 6.00 x 31.0 mm

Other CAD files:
EZCase/CaseShape_EZ.sldprt

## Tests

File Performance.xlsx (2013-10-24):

Description | Name | Max I
MCU | ATSAM3X8EA-AU | 200 | mA
BTLE | BLE112 | 36 | mA
MIDI | VS1053 | 75 | mA
LED Driver | CD4511BPW | 175 | mA
LED Display | LDD-F304NI-RA | 150 | mA
 | TOTAL | 636
 |  | 954
 |  | 1A

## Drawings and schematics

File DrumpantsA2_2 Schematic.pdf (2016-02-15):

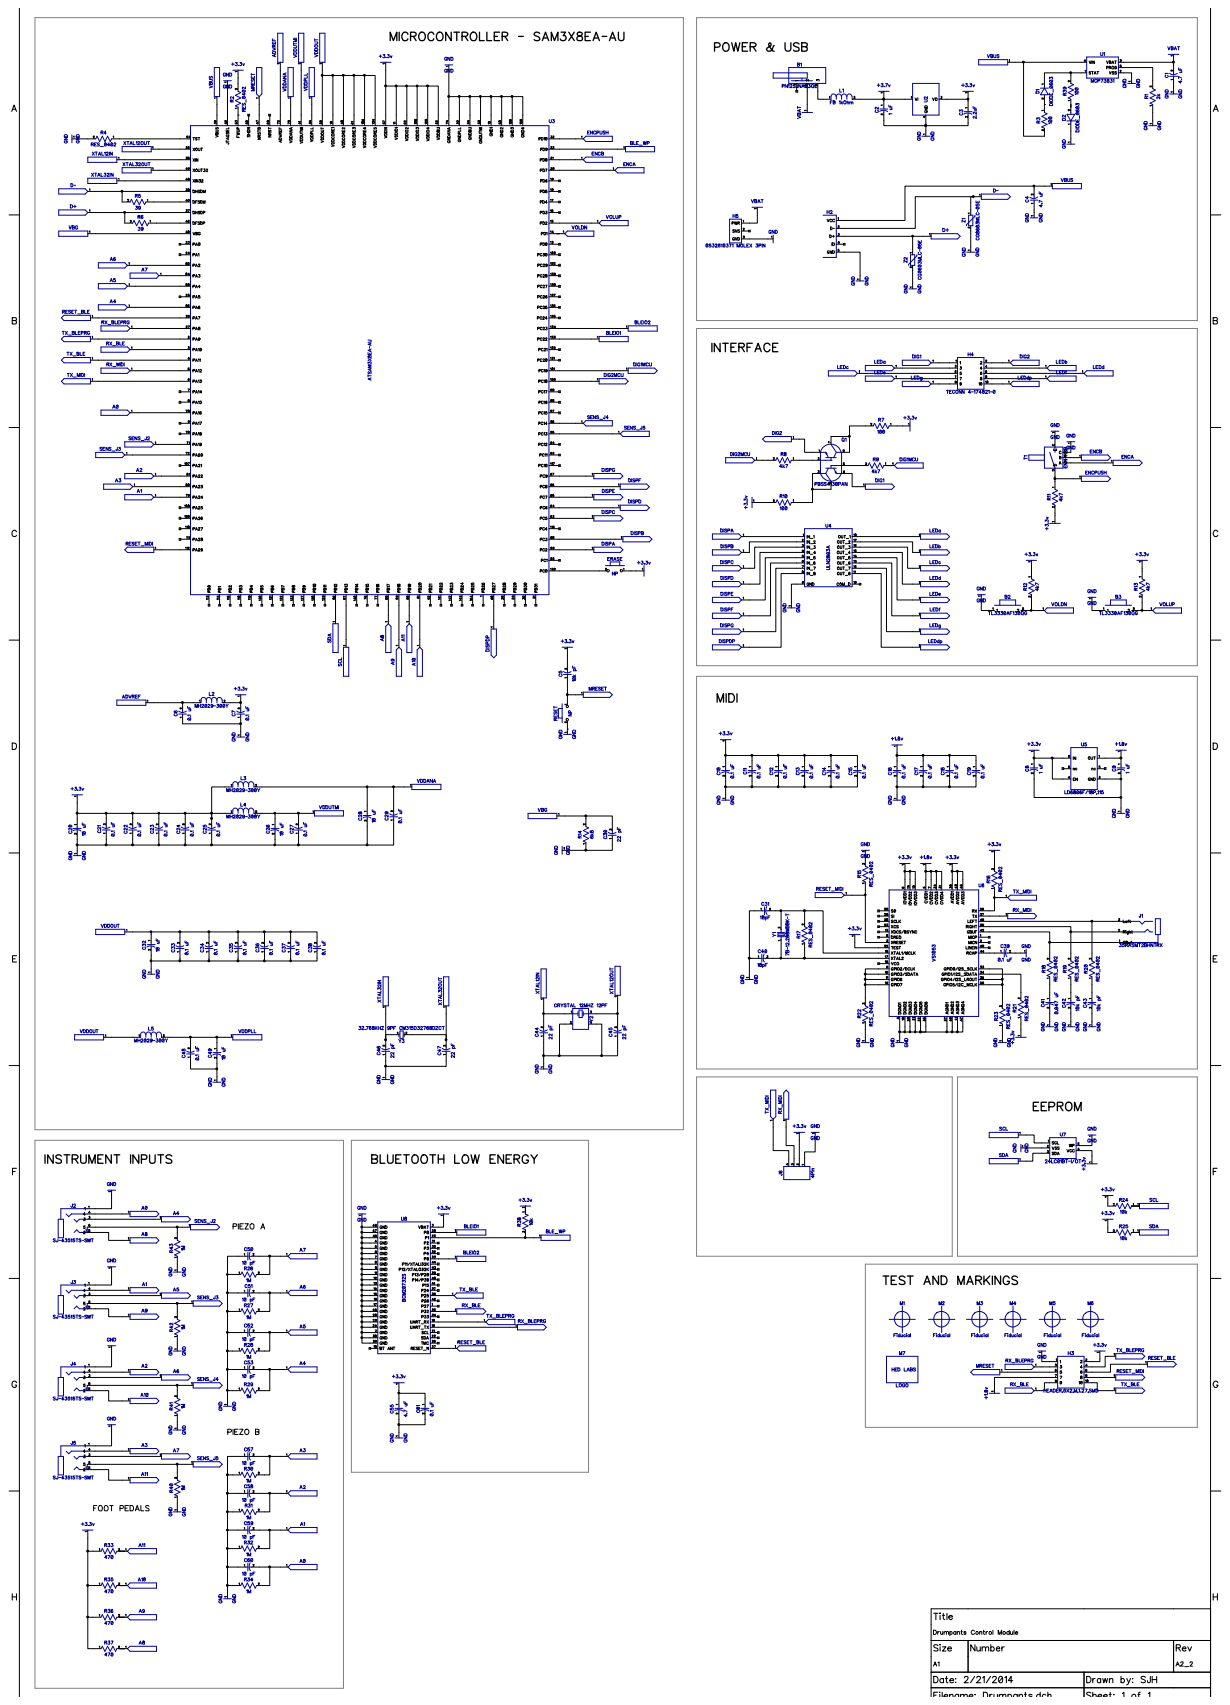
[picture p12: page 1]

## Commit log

2013-10-24 First Commit: board done
    [Arduino_DUE_V02b.brd, Arduino_DUE_V02b.sch, BOM.csv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]
2013-10-25 Made BOM
    [BOM.xlsx]
2014-01-12 Working on REVA case and board (Beta release version)
    [Arduino_DUE_V02b.brd, Arduino_DUE_V02b.sch, BOM.csv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]
2014-01-13 Working on smoothed out version of Case. Updated schematic with power switch fix.
    [Bottom_EZ.sldprt, CaseShape_EZ.sldprt, DrumpantsCase.SLDASM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]
2014-04-06 version A1 - preproduction beta
    [Displays.xlsx, DrumpantsCase.SLDASM, DrumpantsOuterShell.sldprt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]
2014-04-20 Updates after testing Beta Boards (A1)
2014-04-20 added logo. changes to ground plane
2014-05-12 changed BOM & resistor values. Sent to accutrace for assy.
    [Drumpants_A1_BOM_rev2.xlsx, Drumpants_A2_BOM_5-10-2014.xlsx]
2014-05-28 fixes to BOM - 5/14/2013
    [Drumpants_A2_BOM_5-10-2014.xlsx, Drumpants_A2_BOM_5-12-2014.xlsx, Drumpants_A2_BOM_5-14-2014.xlsx]
2014-06-12 Version A2.1 Switched around battery power and ground. Successful proto run from Accutrace.
2014-07-31 Version A2.2 - Added pulldown resistors for jack sense pins
2015-01-14 Version A2.3 - reduced footprint of 0402 components to stop tombstoning. Fixed minimum 0.25mm gap.
2015-02-05 Version 2.4 - adjusted 0402 pad & solder mask size further
2016-02-15 Added Schematic PDF and image files
